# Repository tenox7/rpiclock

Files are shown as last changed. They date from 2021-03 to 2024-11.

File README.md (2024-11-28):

# Raspberry PI Zero WiFi-NTP 7-Segment Desktop Clock

Simple WiFi NTP desktop clock with a large 7-segment display. Built on Raspberry PI Zero.

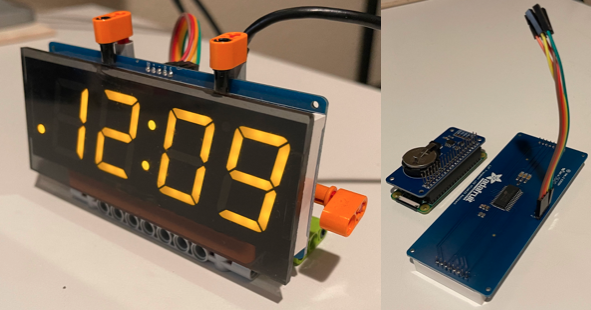
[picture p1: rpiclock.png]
RPI Zero Clock


With LED dot NTP synchronization indicator...

## Why?

* Computers and mobile devices have been using NTP, GSM/GPRS, GPS/GNSS to synchronize time for decades. Desktop / wall and alarm clocks still live in 19th century.
* Changing time twice a year due to retarded DST sucks ass.
* I want to have an indication to see if the time is accurate (synchronized) or not.
* Maybe I want to have Stratum 1 desktop clock.

## Hardware BOM
* [Raspberry PI Zero with WiFi and GPIO Headers](https://www.raspberrypi.org/products/raspberry-pi-zero/)
* [Adafruit 1.2" 7-Segment Display with I2C Backpack](https://www.adafruit.com/product/1270)
* Breadboard Wires
* Optional [Abelectronics RTC Pi Backup Hat](https://www.abelectronics.co.uk/p/70/rtc-pi)
* Optional [Adafruit VEML7700 Lux Sensor](https://www.adafruit.com/product/4162)
* USB power supply and cable
* Case, either 3D printed or make your own
* [Screen](https://www.tapplastics.com/product/plastics/cut_to_size_plastic/acrylic_sheets_transparent_colors/519), Size: 120 x 50 x 3mm

## Building the hardware

### Wiring GPIO to Adafruit Segment Display I2C
* RPi `3.3V` to 7-Segment Display `IO` (V_IO)
* RPi `5V` to 7-Segment Display `+` (+5V)
* RPi `GND` to 7-Segment Display `-` (GND)
* RPi `SCL` to 7-Segment Display `C` (SCL)
* RPi `SDA` to 7-Segment Display `D` (SDA)

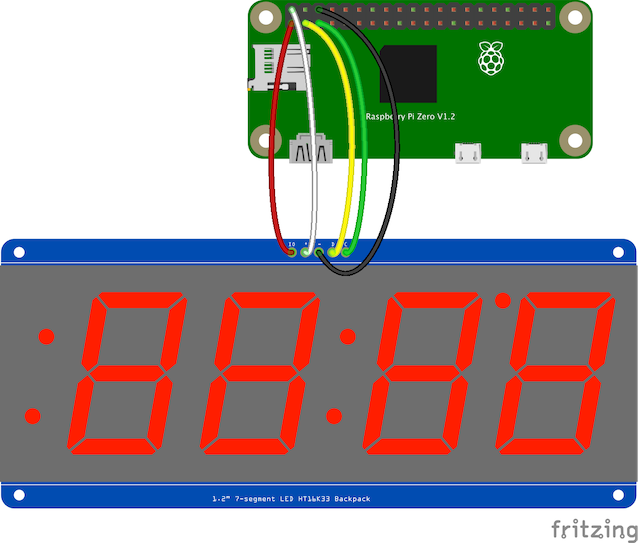
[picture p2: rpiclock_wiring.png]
Wiring Diagram


### Optional RTC Backup Battery Hat

RTC is not required and almost never used while using NTP. However in case of power loss AND internet/wifi/router not being up before Raspberry PI boots, you will get time from *fake-hwclock*, which is no use. RTC backup will make your time accurate in this rare circumstance.

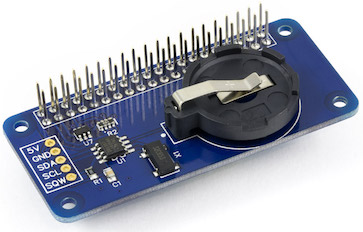
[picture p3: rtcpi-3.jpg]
RTC HAT


There are many RTC backup modules available on the market, [this one](https://www.abelectronics.co.uk/p/70/rtc-pi) is Pi Zero sized.

Install RTC Hat between PI GPIO and wires going to the display. Make sure you install the coin battery before powering it on. The vendor warns that operation without battery will damage the board. Follow instructions below for software setup.

### Advanced - GSM/GPRS/GPS/GNSS Hat

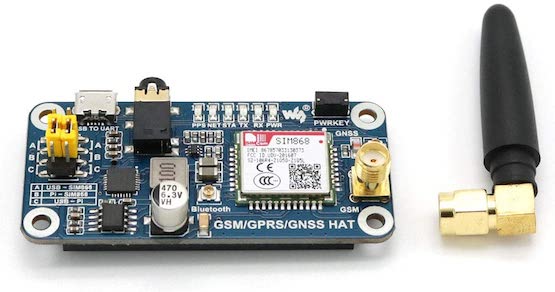
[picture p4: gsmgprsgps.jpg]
GSM/GPRS/GPS HAT


A complete overkill but you can also get time from:

* GSM tower via [NITZ](https://en.wikipedia.org/wiki/NITZ) (no paid subscription required)
* GSM network location (CLBS / CIPGSMLOC)
* GPRS network location (AGPS)
* GNSS/GPS/COMPASS/etc. GPS based time

You can use one of [these hats](https://www.amazon.com/gp/product/B076CPX4NN/) or similar. [MAX-M8Q](https://www.waveshare.com/max-m8q-gnss-hat.htm) has passthrough GPIO and awesome Raspberry PI and [NTP setup instructions](https://www.waveshare.com/wiki/MAX-M8Q_GNSS_HAT).

GSM/GPRS time penetrates buildings like normal cell phone. GPS requires an open sky access but is less dependent on ground infrastructure.

### Light sensor

Rpiclock is set to change brightness based on time of day. A more advanced case would be to use a I2C based Lux sensor to measure ambient light and change display brightness based on input from the sensor. Example sensor [VEML7700](https://www.adafruit.com/product/4162).

### Case

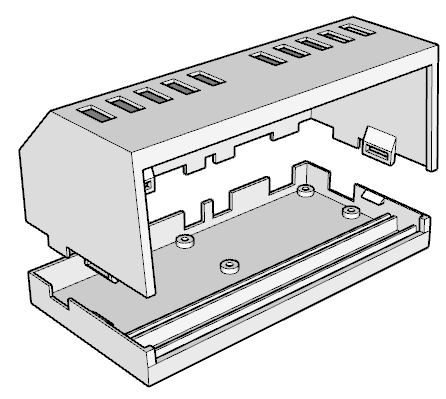
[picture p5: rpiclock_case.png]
3D Printed Case


Download and 3D Print [rpiclock.stl](rpiclock.stl) or design your own case.

## Software configuration

### OS

- Linux
  - [Raspberry Pi OS](https://www.raspberrypi.org/software/operating-systems/) (formerly Raspbian), ubiquitous but is quite of a bloat and slow to boot, but otherwise works well, safe choice.
  - [Alpine](https://www.alpinelinux.org/) easy config transfer between SD cards, doesn't require shutdown, smaller, faster and not bloated. My personal choice.
  - [piCore](http://www.tinycorelinux.net/13.x/armv6/releases/RPi/).
  - [instant-pi](https://github.com/IronOxidizer/instant-pi).
  - [DietPi](https://dietpi.com/) despite promising name is actually quite slow to boot, likely due to Pigbian base.

- FreeBSD - maybe. Super slow to boot and no wlan support on rpi zero.

- NetBSD - no wlan support.

- Plan 9 / 9front - maybe if rewritten in C.

- RISC OS - maybe if rewritten in C.

### Power

Check if Raspberry PI is not experiencing low voltage. You can run `vcgencmd get_throttled`, it should return `0x0`. On Alpine you need to install install `raspberrypi-utils`.

### I2C Interface

Make sure I2C interface is enabled. On Raspbian this is done using `raspi-config` under `Interface Options`.
On Alpine mount mmc boot partition and edit /boot/usercfg.txt (or config.txt). Add: `dtparam=i2c_arm=on`.

Run `i2cdetect -y 1`.

### WiFi, Locale, Timezone, DST, etc.

Make sure to configure WiFi, Locale, Timezone and DST. On Raspbian this is done using `raspi-config`. On Alpine `setup-alpine`.

### NTP

A real NTP daemon supporting RFC5905 is required to be able to get leap indicator and show whether the clock is synchronised or not. You can still use rpiclock without NTP but it will not show the status.

```shell
$ apt install ntp
```

I typically configure it for `pool.ntp.org` and my local wifi router, which has battery backup for time.

### RTC hwclock (optional)

Skip this if not using an RTC HAT.

#### Raspbian

```shell
$ sudo apt remove fake-hwclock
$ sudo echo dtoverlay=i2c-rtc,ds1307 >> /boot/config.txt
$ sudo echo rtc-ds1307 >> /etc/modules
$ sudo echo '5 * * * * *    root   /sbin/hwclock -w' >> /etc/crontab
```

Edit `/lib/udev/hwclock-set`, remove following lines:

```
if [ -e /run/systemd/system ] ; then
  exit 0
fi
```

#### Alpine

Mount mmc card under /media/mmcblk0p1 to write to usercfg.txt.

```shell
# mount -o remount,rw /media/mmcblk0p1
# echo dtparam=i2c_arm=on >> /media/mmcblk0p1/usercfg.txt
# echo dtoverlay=i2c-rtc,ds1307 >> /media/mmcblk0p1/usercfg.txt
# echo i2c-dev >> /etc/modules
# echo rtc-ds1307 >> /etc/modules
# echo '5 * * * * /sbin/hwclock -w -l' >> /etc/crontabs/root
# sed -i 's/^clock="UTC"/clock="local"/' /etc/conf.d/hwclock
# rc-update del swclock boot
# lbu ci -d
```

Reboot, check if hwclock works. Ideally this should be done before WiFi is configured so NTP won't interfere with RTC testing. You can also disable chrony from start on boot to test.

#### Troubleshooting

```shell
# lsmod | grep i2c
# lsmod | grep ds1307
# apk add --no-cache i2c-tools
# i2cdetect -y 1
```

### Clock Service Install

Download the binary from [Releases](https://github.com/tenox7/rpiclock/releases).

#### Raspbian

If using `systemd` Download [Service File](https://raw.githubusercontent.com/tenox7/rpiclock/main/rpiclock.service) and move in to `~/.config/systemd/user/rpiclock.service`. Make sure the right path to the binary is specified.

```shell
$ loginctl enable-linger $USER
$ systemctl --user daemon-reload
$ systemctl --user enable --now rpiclock.service
```

#### Alpine

You may already done this for the RTC, if not:

```shell
# mount -o remount,rw /media/mmcblk0p1
# echo dtparam=i2c_arm=on >> /media/mmcblk0p1/usercfg.txt
# echo i2c-dev >> /etc/modules
# lbu ci -d
```

Setup NTP:

```shell
# setup-ntp chrony
# echo "allow 127.0.0.1" >> /etc/chrony/chrony.conf
# echo "makestep 1.0 3" >> /etc/chrony/chrony.conf
# rc-service chronyd restart
# lbu ci -d
```

RPIClock service:

```shell
# wget -O /sbin/rpiclock https://github.com/tenox7/rpiclock/releases/download/1.2/rpiclock
# chmod 755 /sbin/rpiclock
# lbu include /sbin/rpiclock
# wget -O /etc/init.d/rpiclock https://raw.githubusercontent.com/tenox7/rpiclock/refs/heads/main/rpiclock.openrc
# chmod 755 /etc/init.d/rpiclock
# lbu include /etc/init.d/rpiclock
# rc-update add rpiclock default
# rc-service rpiclock start
# lbu ci -d
```

Once you're done with the setup, you can distribute `/media/mmcblk0p1/hostname.apkovl.tar.gz` and `usercfg.txt` to other systems.

## References
* [Adafruit Wiring and Setup](https://learn.adafruit.com/adafruit-led-backpack/python-wiring-and-setup-d74df15e-c55c-487a-acce-a905497ef9db)
* [RTC Pi setup on RPI OS](https://www.abelectronics.co.uk/kb/article/30/rtc-pi-on-a-raspberry-pi-raspbian-jessie)
* [HT16K33 Golang Library](https://github.com/rafalop/sevensegment)

## Legal

* Copyright (c) 2024 by Antoni Sawicki

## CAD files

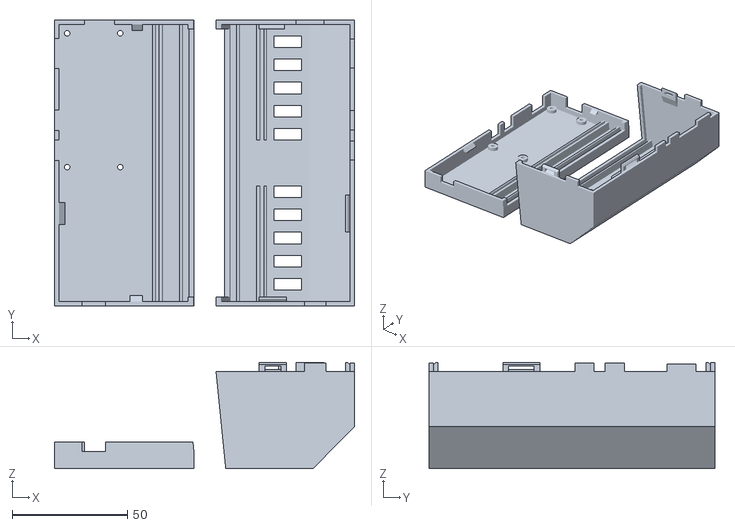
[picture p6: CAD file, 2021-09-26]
rpiclock.stl
130.0 x 124.0 x 46.0

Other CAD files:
rpiclock.skp

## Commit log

2021-03-16 add wiring diagram
    [rpiclock.fzz]
2021-03-16 update wiring instruction
2021-06-23 add 3d print case
    [bottom.skp, bottom.stl, top.skp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]
2021-06-23 case drawing
2021-06-23 rename case file
2021-06-23 rename case files
    [bottom.skp, bottom.stl, top.skp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]
2021-06-23 add link to stl file
2021-06-23 update case pic
2021-07-24 update i2cdetect
2021-08-14 thicker walls
    [rpiclock.skp, rpiclock.stl]
2021-09-26 make walls and clips thicker
    [rpiclock.skp, rpiclock.stl]
2021-09-26 updated bom
2023-02-20 i2c for the display
2024-11-24 call bright from timer
2024-11-25 implement interface for display driver
2024-11-27 initial impl of a driver for 7segment
2024-11-28 i2c dev module for alpine
2024-12-04 add dummy display driver
2024-12-04 dummy driver to actually use fmt.printf instead of debug
